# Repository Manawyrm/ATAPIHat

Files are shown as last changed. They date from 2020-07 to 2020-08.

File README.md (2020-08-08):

ATAPIHat
=============================

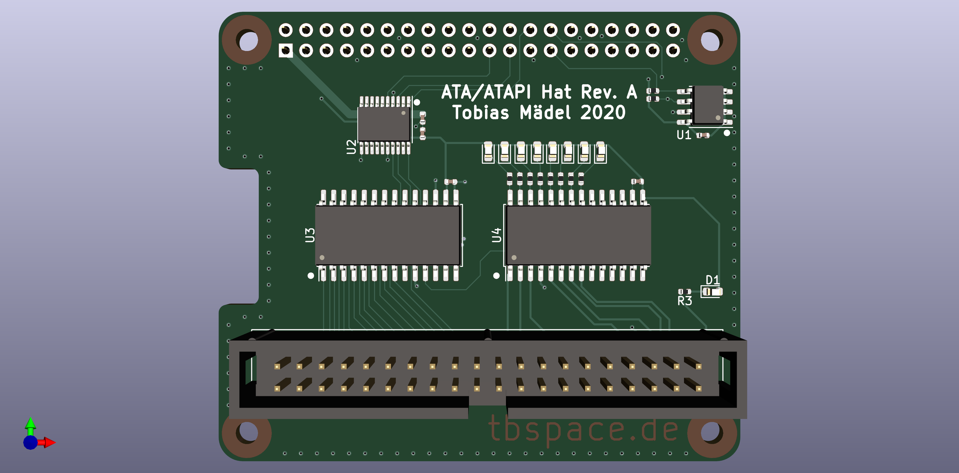
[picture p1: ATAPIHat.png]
PCB


#### Overview

Replaced by https://github.com/Manawyrm/ATAPIHat-SMI  
Directly connected to the GPIOs, much higher speeds.   

**Don't manufacture this board (in either Rev.A or Rev.B).**  
This design isn't optimal at all. 

#### Rev. A Errata
Reset is wrong, is hardpulled to ground. Solution: connect to GPIO17.   
Chip select is non-ideal (solder jumper?)  
Selectable 5V/3.3V on Pin 20 required  
IDE Reset line should be connected to LED7 aka pin 28 of U4  
Signal integrity issues, paralell termination resistors (maybe 120 Ohms) and series termination would be ideal.  

#### Additional info

[Kernel driver](https://github.com/Manawyrm/pata-gpio)  
[Schematic](https://github.com/Manawyrm/ATAPIHat/blob/master/ATAPIHat.pdf)

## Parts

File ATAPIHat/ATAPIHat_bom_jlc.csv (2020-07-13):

Comment | Designator | Footprint | LCSC Part #
100n | C1,C2,C3,C4,C5 | C_0402_1005Metric | C1525
LED | D1 | LED_0603_1608Metric | C72043
Red | D2,D3 | LED_0603_1608Metric | C2286
Yellow | D4,D5 | LED_0603_1608Metric | C72038
Green | D6,D7 | LED_0603_1608Metric | C72043
Blue | D8,D9 | LED_0603_1608Metric | C72041
4.7k | R1,R2,R3,R4,R5,R6,R7,R10,R11 | R_0402_1005Metric | C25900
10k | R8,R9 | R_0402_1005Metric | C25744
AT24CS32 | U1 | SOIC-8_3.9x4.9mm_P1.27mm | C60583
TXS0108EPW | U2 | TSSOP-20_4.4x6.5mm_P0.65mm | C17206
MCP23S17_SO | U3,U4 | SOIC-28W_7.5x17.9mm_P1.27mm | C145413

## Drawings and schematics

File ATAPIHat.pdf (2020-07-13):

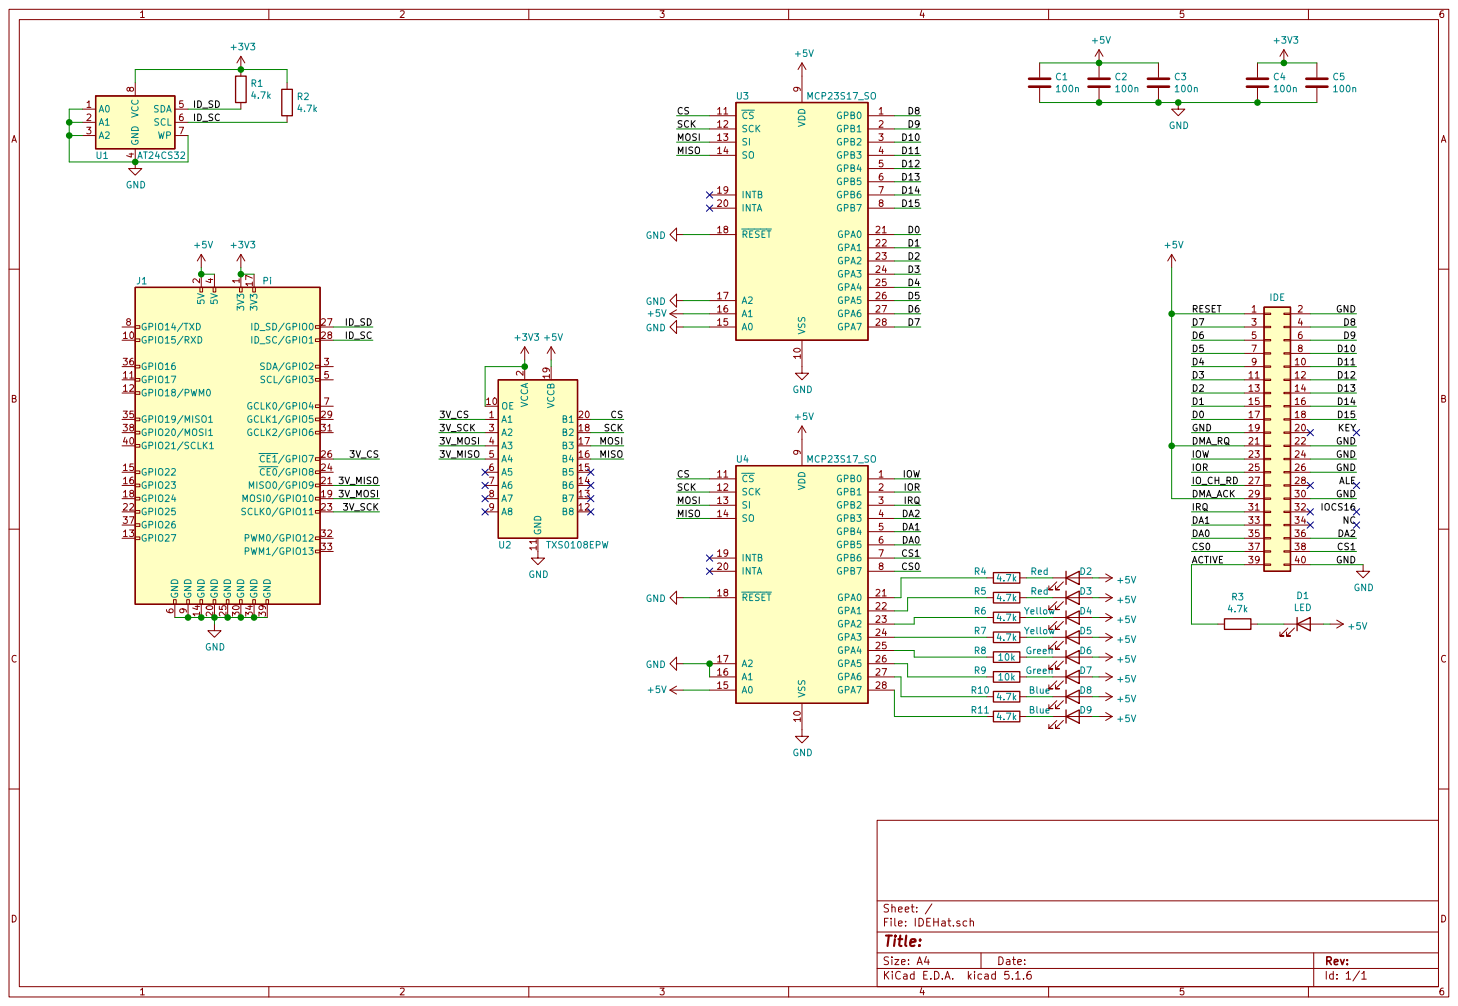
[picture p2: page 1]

4 SDA 5 SCL 6 WP 7 VCC

ALE D12 D13 D14 D15 KEY GND GND GND

Id: 1/1 Title: File: IDEHat.sch Sheet: /

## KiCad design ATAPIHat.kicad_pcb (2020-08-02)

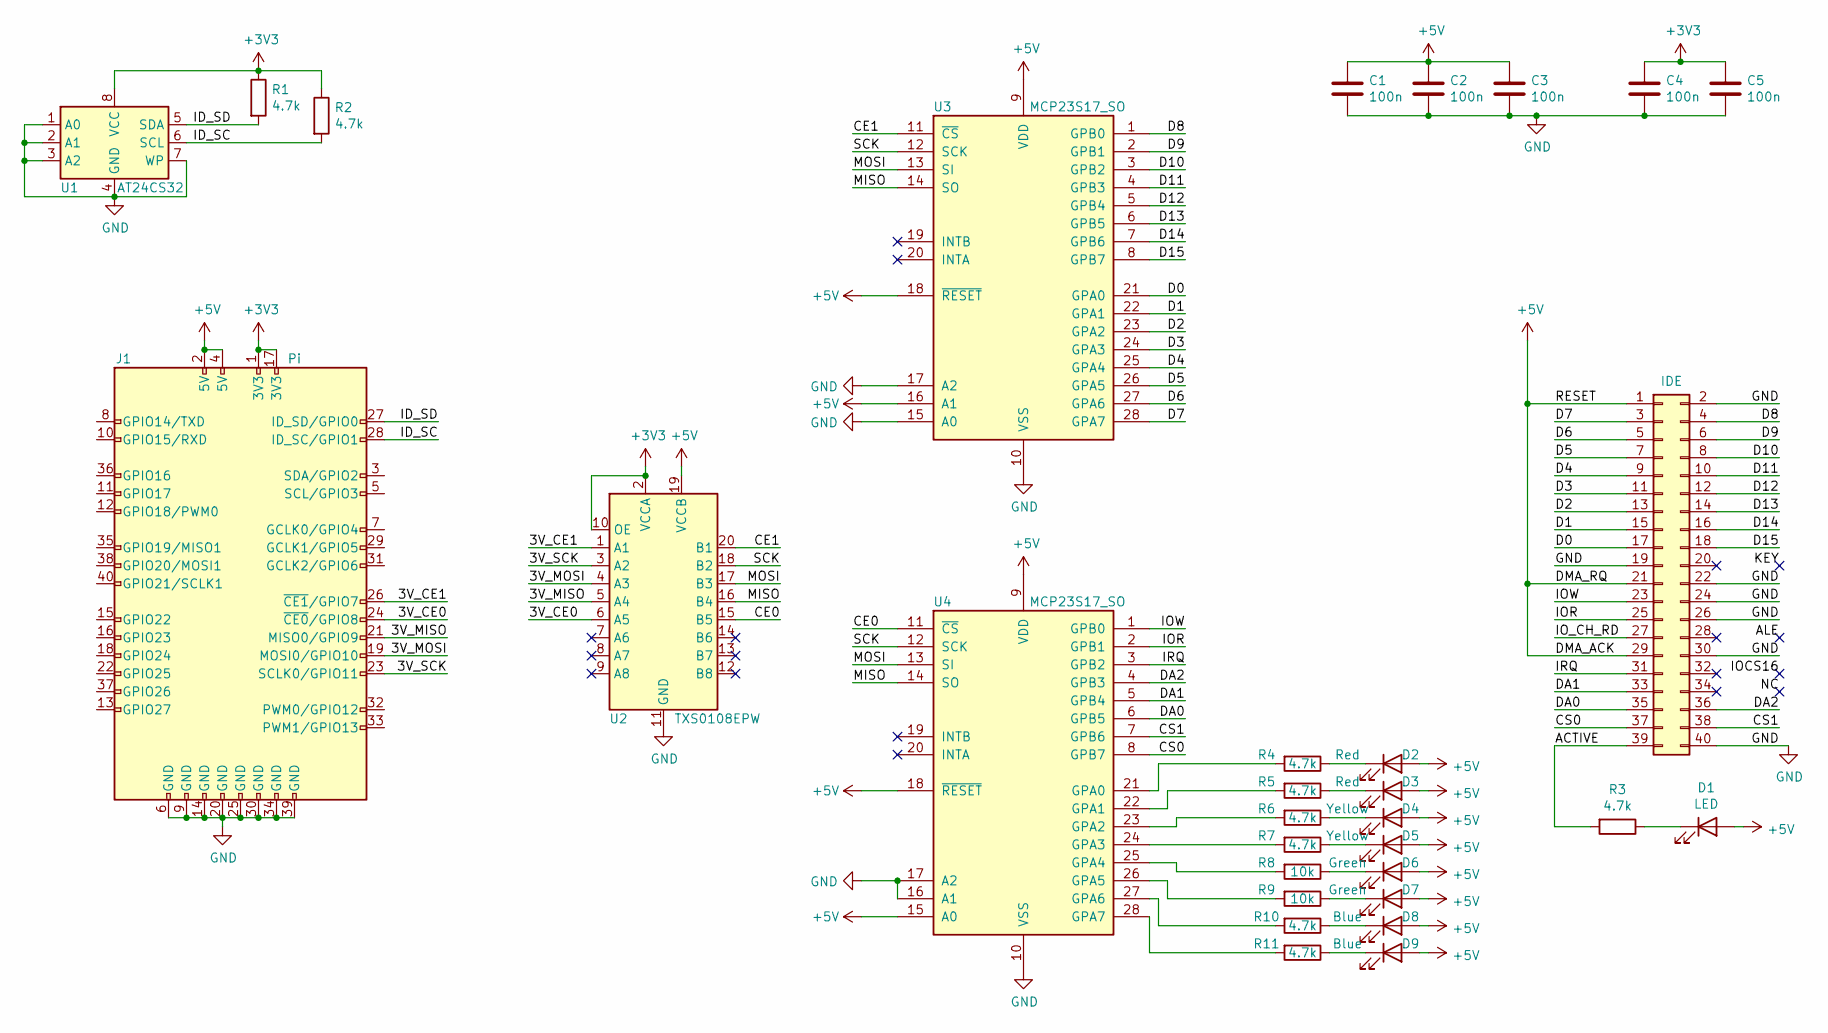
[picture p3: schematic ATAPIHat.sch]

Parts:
C1, C2, C3, C4, C5: 100n; C_0402_1005Metric; LCSC C1525
D1: LED; LED_0603_1608Metric; LCSC C72043
D2, D3: Red; LED_0603_1608Metric; LCSC C2286
D4, D5: Yellow; LED_0603_1608Metric; LCSC C72038
D6, D7: Green; LED_0603_1608Metric; LCSC C72043
D8, D9: Blue; LED_0603_1608Metric; LCSC C72041
J1: Pi; PinSocket_2x20_P2.54mm_Vertical
J2: IDE; IDC-Header_2x20_P2.54mm_Vertical
R1, R2, R3, R4, R5, R6, R7, R10, R11: 4.7k; R_0402_1005Metric; LCSC C25900
R8, R9: 10k; R_0402_1005Metric; LCSC C25744
U1: AT24CS32; SOIC-8_3.9x4.9mm_P1.27mm; LCSC C60583
U2: TXS0108EPW; TSSOP-20_4.4x6.5mm_P0.65mm; LCSC C17206
U3, U4: MCP23S17_SO; SOIC-28W_7.5x17.9mm_P1.27mm; LCSC C145413

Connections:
+3V3: C4.1, C5.1, J1.1 (3V3), J1.17 (3V3), R1.1, R2.1, U1.8 (VCC), U2.2 (VCCA), U2.10 (OE)
+5V: C1.1, C2.1, C3.1, D1.2 (A), D2.2 (A), D3.2 (A), D4.2 (A), D5.2 (A), D6.2 (A), D7.2 (A), D8.2 (A), D9.2 (A), J1.2 (5V), J1.4 (5V), J2.1, J2.21, J2.29, U2.19 (VCCB), U3.9 (VDD), U3.16 (A1), U3.18 (~RESET~), U4.9 (VDD), U4.15 (A0), U4.18 (~RESET~)
/3V_CE0: J1.24 (~CE0~/GPIO8), U2.6 (A5)
/3V_CE1: J1.26 (~CE1~/GPIO7), U2.1 (A1)
/3V_MISO: J1.21 (MISO0/GPIO9), U2.5 (A4)
/3V_MOSI: J1.19 (MOSI0/GPIO10), U2.4 (A3)
/3V_SCK: J1.23 (SCLK0/GPIO11), U2.3 (A2)
/ACTIVE: J2.39, R3.2
/CE0: U2.15 (B5), U4.11 (~CS~)
/CE1: U2.20 (B1), U3.11 (~CS~)
/CS0: J2.37, U4.8 (GPB7)
/CS1: J2.38, U4.7 (GPB6)
/D0: J2.17, U3.21 (GPA0)
/D1: J2.15, U3.22 (GPA1)
/D2: J2.13, U3.23 (GPA2)
/D3: J2.11, U3.24 (GPA3)
/D4: J2.9, U3.25 (GPA4)
/D5: J2.7, U3.26 (GPA5)
/D6: J2.5, U3.27 (GPA6)
/D7: J2.3, U3.28 (GPA7)
/D8: J2.4, U3.1 (GPB0)
/D9: J2.6, U3.2 (GPB1)
/D10: J2.8, U3.3 (GPB2)
/D11: J2.10, U3.4 (GPB3)
/D12: J2.12, U3.5 (GPB4)
/D13: J2.14, U3.6 (GPB5)
/D14: J2.16, U3.7 (GPB6)
/D15: J2.18, U3.8 (GPB7)
/DA0: J2.35, U4.6 (GPB5)
/DA1: J2.33, U4.5 (GPB4)
/DA2: J2.36, U4.4 (GPB3)
/ID_SC: J1.28 (ID_SC/GPIO1), R2.2, U1.6 (SCL)
/ID_SD: J1.27 (ID_SD/GPIO0), R1.2, U1.5 (SDA)
/IOR: J2.25, U4.2 (GPB1)
/IOW: J2.23, U4.1 (GPB0)
/IO_CH_RD: J2.27
/IRQ: J2.31, U4.3 (GPB2)
/MISO: U2.16 (B4), U3.14 (SO), U4.14 (SO)
/MOSI: U2.17 (B3), U3.13 (SI), U4.13 (SI)
/SCK: U2.18 (B2), U3.12 (SCK), U4.12 (SCK)
GND: C1.2, C2.2, C3.2, C4.2, C5.2, J1.6 (GND), J1.9 (GND), J1.14 (GND), J1.20 (GND), J1.25 (GND), J1.30 (GND), J1.34 (GND), J1.39 (GND), J2.2, J2.19, J2.22, J2.24, J2.26, J2.30, J2.40, U1.1 (A0), U1.2 (A1), U1.3 (A2), U1.4 (GND), U1.7 (WP), U2.11 (GND), U3.10 (VSS), U3.15 (A0), U3.17 (A2), U4.10 (VSS), U4.16 (A1), U4.17 (A2)
unnamed: D1.1 (K), R3.1
unnamed: D2.1 (K), R4.1
unnamed: D3.1 (K), R5.1
unnamed: D4.1 (K), R6.1
unnamed: D5.1 (K), R7.1
unnamed: D6.1 (K), R8.1
unnamed: D7.1 (K), R9.1
unnamed: D8.1 (K), R10.1
unnamed: D9.1 (K), R11.1
unnamed: R4.2, U4.21 (GPA0)
unnamed: R5.2, U4.22 (GPA1)
unnamed: R6.2, U4.23 (GPA2)
unnamed: R7.2, U4.24 (GPA3)
unnamed: R8.2, U4.25 (GPA4)
unnamed: R9.2, U4.26 (GPA5)
unnamed: R10.2, U4.27 (GPA6)
unnamed: R11.2, U4.28 (GPA7)

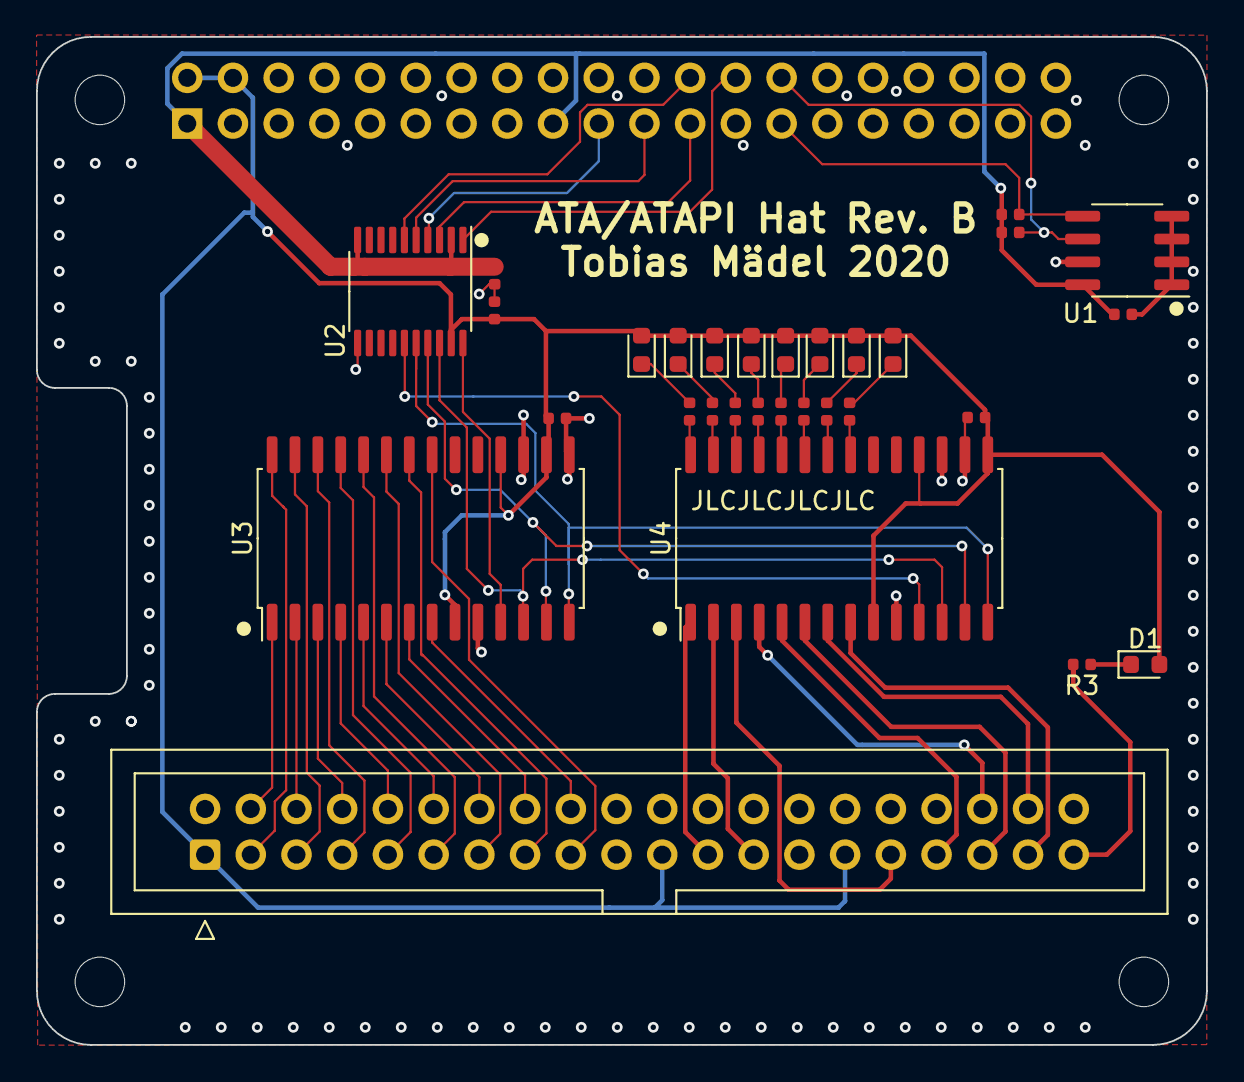
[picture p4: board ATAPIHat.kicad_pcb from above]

Board: 2 copper layers, 65.0 x 56.0 mm, 31 parts (1 on the bottom side), 57 nets.

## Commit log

2020-07-13 Rename to ATAPIHat
    [ATAPIHat-B_Cu.gbl, ATAPIHat-B_Mask.gbs, ATAPIHat-B_Paste.gbp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]
2020-08-02 ATAPIHat Rev A Errata
    [ATAPIHat.kicad_pcb, ATAPIHat.sch]
